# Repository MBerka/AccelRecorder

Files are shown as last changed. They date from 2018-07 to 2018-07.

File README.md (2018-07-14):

This project contains PCB and firmware files for the AccelRecorder wearable, capable of recording tri-axial accelerations or, with firmware adjustments, communicating with a combined accelerometer/gyroscope chip. The byte-encoded output of the firmware can be parsed and interpreted with the PC-side software of the AccelPanel repository.

The Eagle files in /PCB that can be etched chemically via toner transfer, or exported for commercial PCB manufacturing.

The C project was written and compiled through Atmel Studio 7. Compiled binaries are available in /Hardware/Debug.

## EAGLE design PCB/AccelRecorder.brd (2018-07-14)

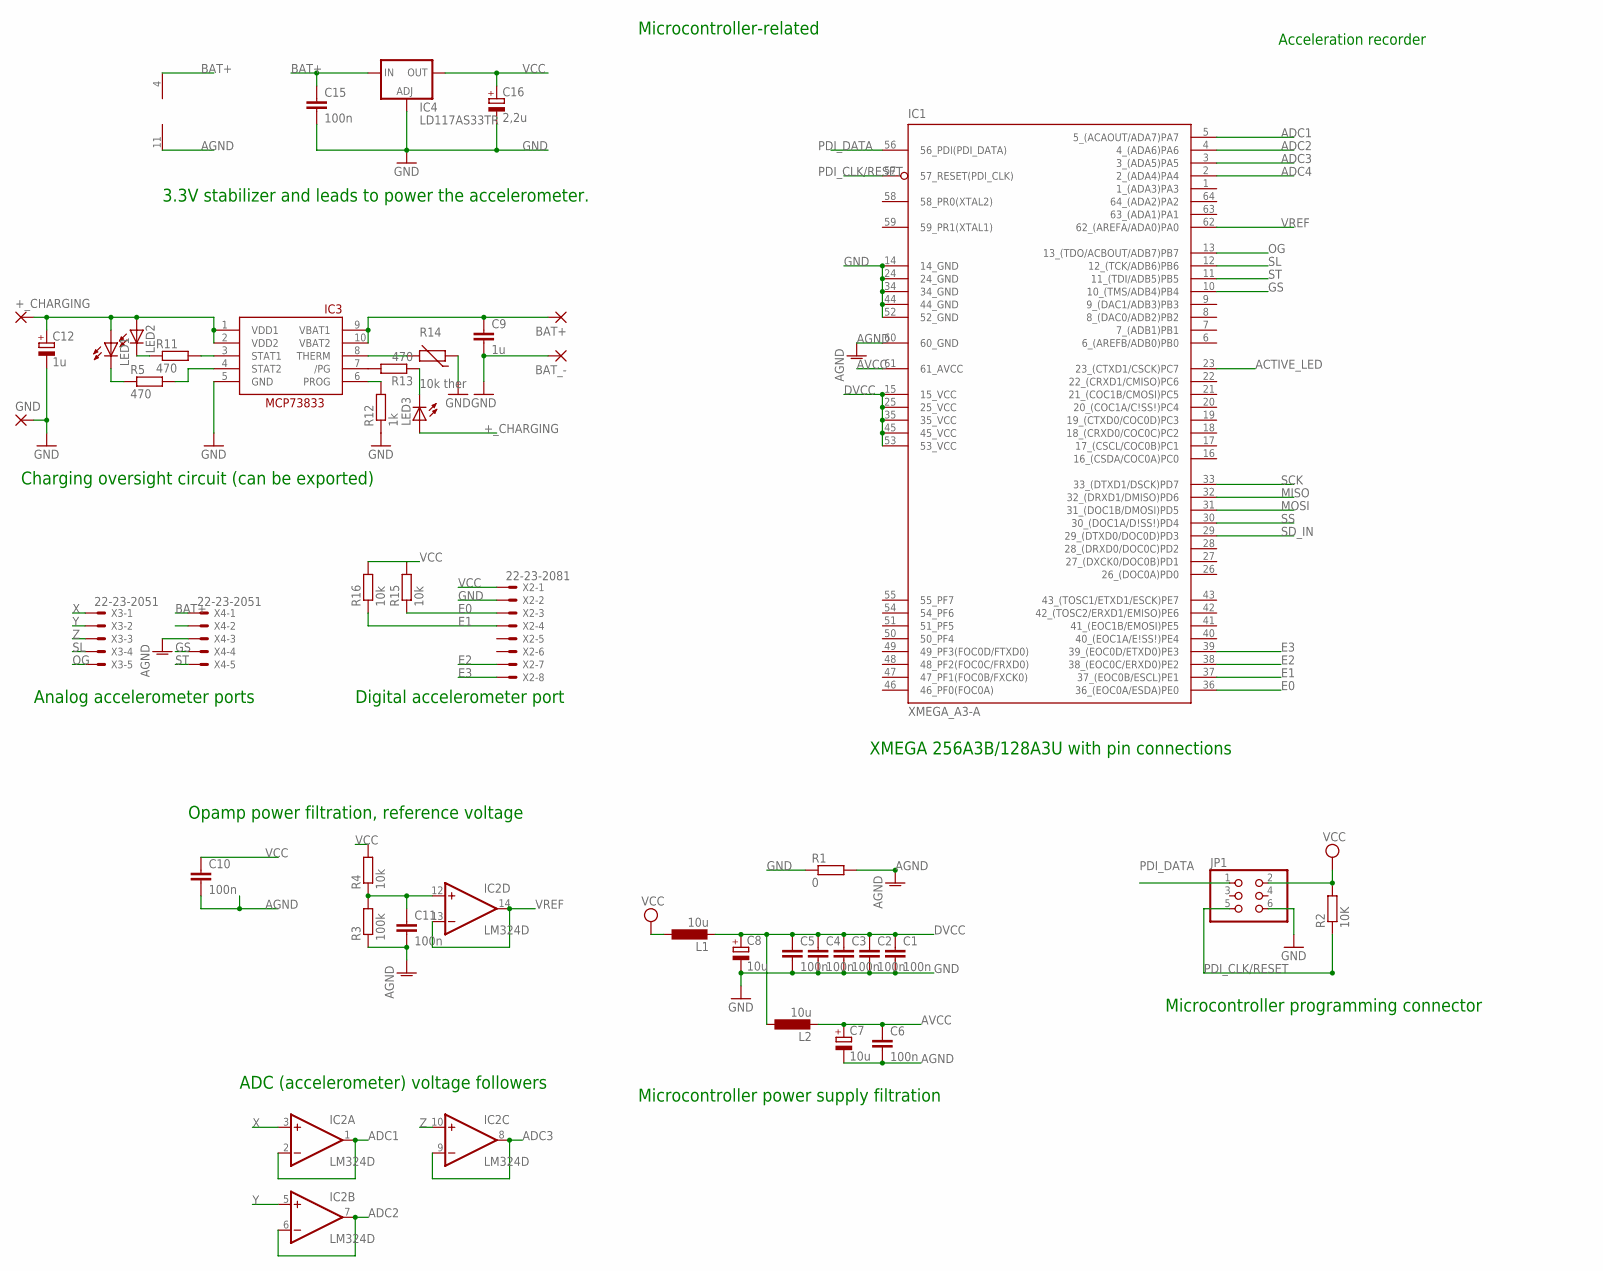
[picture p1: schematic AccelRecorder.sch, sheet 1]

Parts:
+_CHARGING: SMD2; SMD1,27-2,54
BAT+: SMD2; SMD1,27-2,54
BAT_-: SMD2; SMD1,27-2,54
C1, C2, C3, C4, C5, C6, C15: 100n; C0805K
C7, C8: 10u; SANYO-OSCON_SMD_B6
C9: 1u; C1206
C10, C11: 100n; C0805
C12: 1u; SANYO-OSCON_SMD_B6
C16: 2,2u; SANYO-OSCON_SMD_B6
GND: SMD2; SMD1,27-2,54
IC1: XMEGA_A3-A; TQFP64
IC2: LM324D; SO14
IC3: MCP73833-UN; MSOP10
IC4: LD117AS33TR; SOT223
JP1: PINHD-2X3; 2X03
L1, L2: 10u; L3225M
LED1, LED2, LED3: LED3MM
R1: 0; M1206
R2: 10K; M1206
R3: 100k; M1206
R4, R15, R16: 10k; M1206
R5, R11, R13: 470; R0805
R12: 1k; R0805
R14: 10k ther; RS-2,5
X2: 22-23-2081
X3, X4: 22-23-2051

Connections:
+_CHARGING: +_CHARGING.1, C12.+, IC3.1 (VDD1), IC3.2 (VDD2), LED1.A, LED2.A, LED3.A
ACTIVE_LED: IC1.23 (23_(CTXD1/CSCK)PC7); also elsewhere on the board
ADC1: IC1.5 (5_(ACAOUT/ADA7)PA7), IC2.1 (OUT), IC2.2 (-IN)
ADC2: IC1.4 (4_(ADA6)PA6), IC2.6 (-IN), IC2.7 (OUT)
ADC3: IC1.3 (3_(ADA5)PA5), IC2.8 (OUT), IC2.9 (-IN)
ADC4: IC1.2 (2_(ADA4)PA4)
AGND: C6.2, C7.-, C10.2, C11.2, IC1.60 (60_GND), IC2.11 (V-), R1.2, R3.1, X4.3
AVCC: C6.1, C7.+, IC1.61 (61_AVCC), L2.2
BAT+: BAT+.1, C9.1, C15.1, IC2.4 (V+), IC3.9 (VBAT1), IC3.10 (VBAT2), IC4.3 (IN), X4.1
DVCC: C1.1, C2.1, C3.1, C4.1, C5.1, C8.+, IC1.15 (15_VCC), IC1.25 (25_VCC), IC1.35 (35_VCC), IC1.45 (45_VCC), IC1.53 (53_VCC), L1.2, L2.1
E0: IC1.36 (36_(EOC0A/ESDA)PE0), R15.1, X2.3
E1: IC1.37 (37_(EOC0B/ESCL)PE1), R16.1, X2.4
E2: IC1.38 (38_(EOC0C/ERXD0)PE2), X2.7
E3: IC1.39 (39_(EOC0D/ETXD0)PE3), X2.8
GND: BAT_-.1, C1.2, C2.2, C3.2, C4.2, C5.2, C8.-, C9.2, C12.-, C15.2, C16.-, GND.1, IC1.14 (14_GND), IC1.24 (24_GND), IC1.34 (34_GND), IC1.44 (44_GND), IC1.52 (52_GND), IC3.5 (GND), IC4.1 (ADJ), JP1.6, R1.1, R12.1, R14.1, X2.2; also elsewhere on the board
GS: IC1.10 (10_(TMS/ADB4)PB4), X4.4
MISO: IC1.32 (32_(DRXD1/DMISO)PD6); also elsewhere on the board
MOSI: IC1.31 (31_(DOC1B/DMOSI)PD5); also elsewhere on the board
unnamed: IC3.7 (/PG), R13.2
unnamed: LED3.K (C), R13.1
unnamed: IC3.3 (STAT1), R11.2
unnamed: LED2.K (C), R11.1
unnamed: C11.1, IC2.12 (+IN), R3.2, R4.1
unnamed: IC3.6 (PROG), R12.2
unnamed: IC3.8 (THERM), R14.2
unnamed: LED1.K (C), R5.1
unnamed: IC3.4 (STAT2), R5.2
OG: IC1.13 (13_(TDO/ACBOUT/ADB7)PB7), X3.5
PDI_CLK/RESET: IC1.57 (57_RESET(PDI_CLK)), JP1.5, R2.1
PDI_DATA: IC1.56 (56_PDI(PDI_DATA)), JP1.1
SCK: IC1.33 (33_(DTXD1/DSCK)PD7); also elsewhere on the board
SD_IN: IC1.29 (29_(DTXD0/DOC0D)PD3); also elsewhere on the board
SL: IC1.12 (12_(TCK/ADB6)PB6), X3.4
SS: IC1.30 (30_(DOC1A/D\!SS\!)PD4); also elsewhere on the board
ST: IC1.11 (11_(TDI/ADB5)PB5), X4.5
VCC: C10.1, C16.+, IC4.4 (OUT), JP1.2, L1.1, R2.2, R4.2, R15.2, R16.2, X2.1; also elsewhere on the board
VREF: IC1.62 (62_(AREFA/ADA0)PA0), IC2.13 (-IN), IC2.14 (OUT)
X: IC2.3 (+IN), X3.1
Y: IC2.5 (+IN), X3.2
Z: IC2.10 (+IN), X3.3

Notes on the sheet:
Microcontroller-related
Microcontroller programming connector
Microcontroller power supply filtration
XMEGA 256A3B/128A3U with pin connections
Acceleration recorder
Opamp power filtration, reference voltage
ADC (accelerometer) voltage followers
Charging oversight circuit (can be exported)
3.3V stabilizer and leads to power the accelerometer.
Analog accelerometer ports
Digital accelerometer port

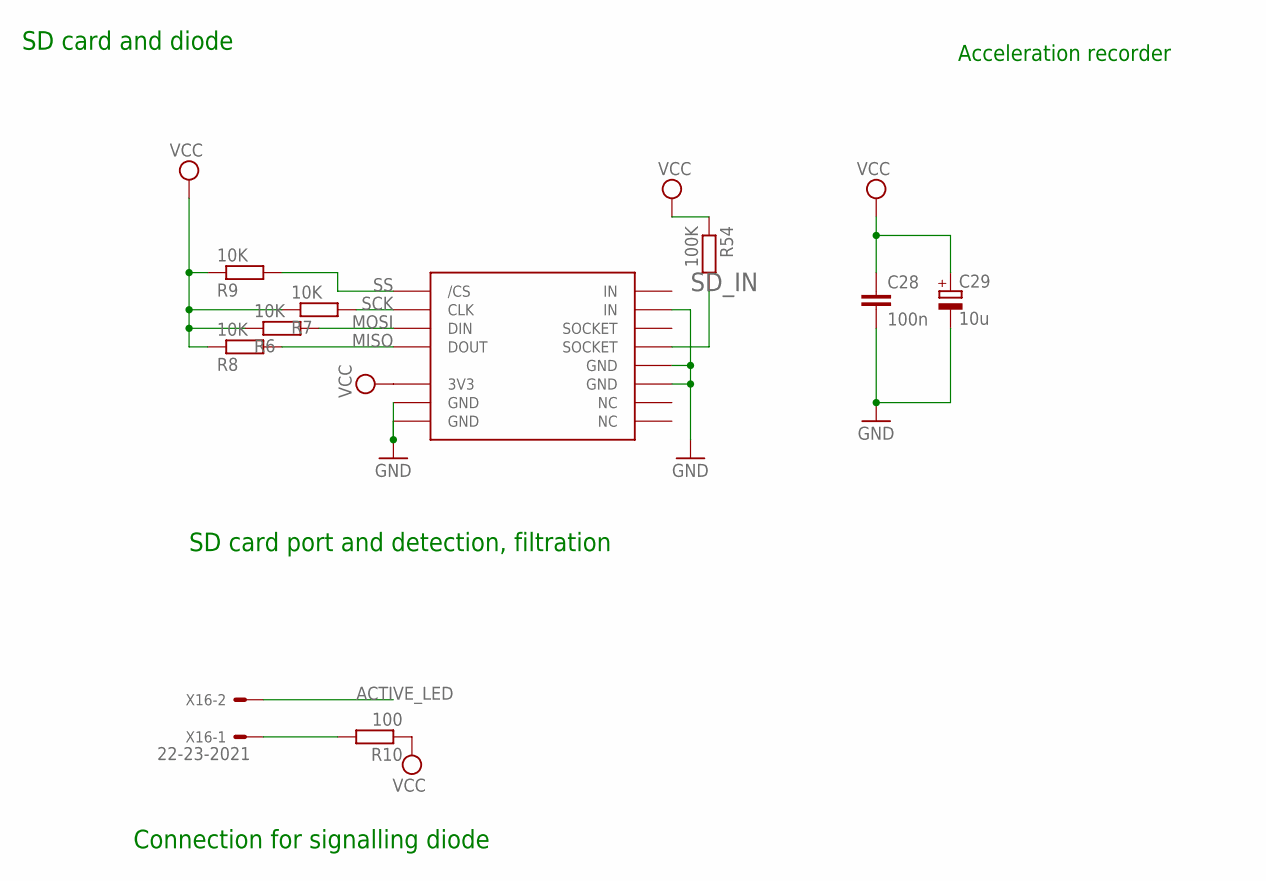
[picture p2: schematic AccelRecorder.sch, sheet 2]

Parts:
C28: 100n; C0805K
C29: 10u; SANYO-OSCON_SMD_B6
R6, R7, R8, R9: 10K; M1206
R10: 100; M1206
R54: 100K; M1206
U$1: MMC; MMC_SOCKET
X16: 22-23-2021; MPN 22-23-2021

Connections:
ACTIVE_LED: X16.2; also elsewhere on the board
GND: C28.2, C29.-, U$1.GND@1 (GND), U$1.GND@2 (GND), U$1.GND@3 (GND), U$1.GND@4 (GND), U$1.IN@2 (IN); also elsewhere on the board
MISO: R8.2, U$1.DOUT; also elsewhere on the board
MOSI: R6.2, U$1.DIN; also elsewhere on the board
unnamed: R10.2, X16.1
SCK: R7.2, U$1.CLK; also elsewhere on the board
SD_IN: R54.2, U$1.P$2 (SOCKET); also elsewhere on the board
SS: R9.2, U$1./CS; also elsewhere on the board
VCC: C28.1, C29.+, R6.1, R7.1, R8.1, R9.1, R10.1, R54.1, U$1.3V3; also elsewhere on the board

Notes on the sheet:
SD card and diode
SD card port and detection, filtration
Acceleration recorder
Connection for signalling diode

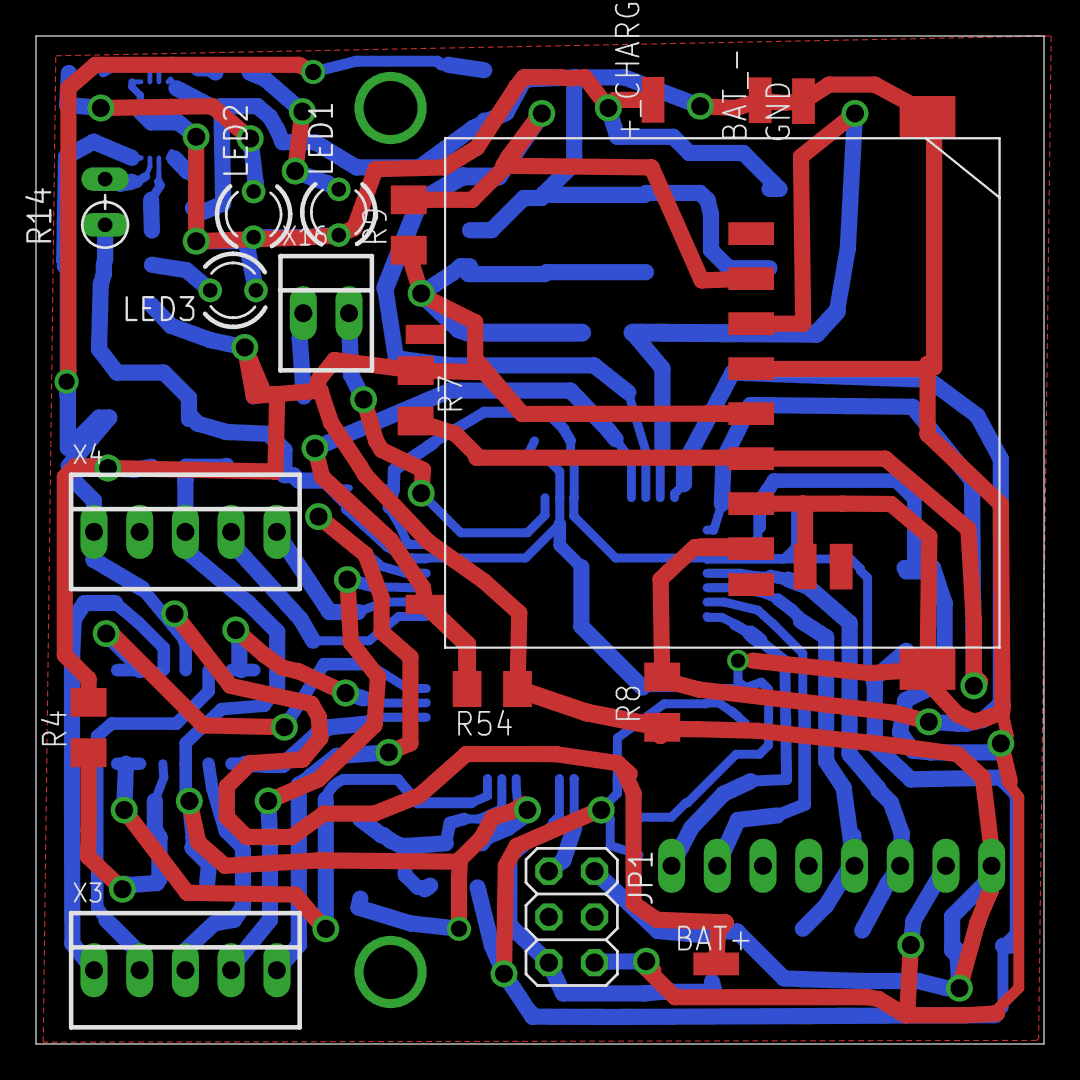
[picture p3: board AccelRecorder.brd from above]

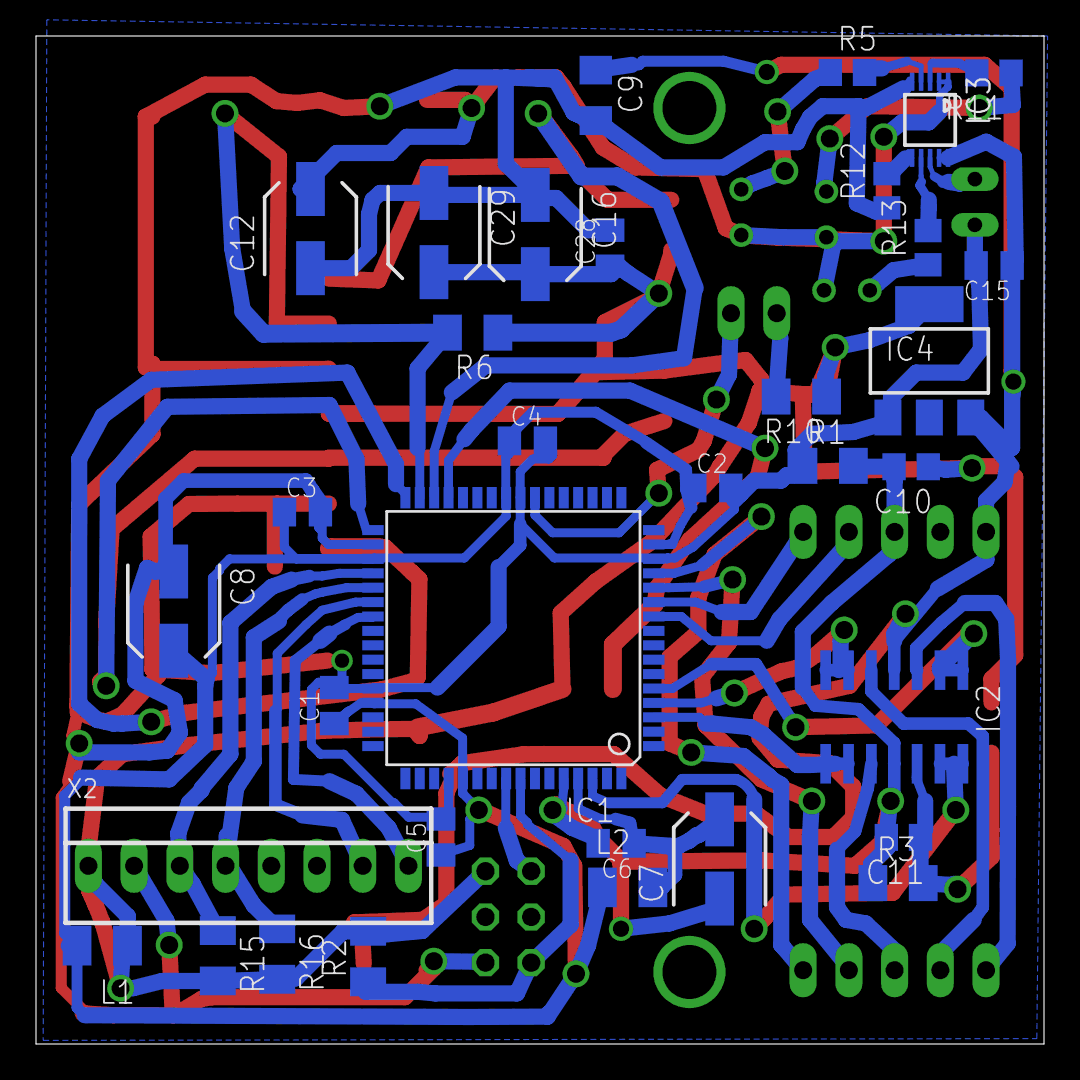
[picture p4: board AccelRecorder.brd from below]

Board: 2 copper layers, 56.0 x 56.0 mm, 52 parts (34 on the bottom side), 40 nets.

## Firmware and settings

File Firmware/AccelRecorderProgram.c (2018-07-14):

/*
 * AccelRecorderProgram.c
 * 26bytes/meas*300meas/s*3600s/h*48h
 *
 * Created: 2014-07-04 12:00:00
 * Author: Martin Berka, file access process reused from code by Marek Zylinski
 * When SD card is inserted, activates accelerometer and  records 300 
 * measurements/s from 3 ADC channels to SD Card while flashing diode.
 * Otherwise, enters low-power mode.
 */ 

#define F_CPU 16000000UL

#include <avr/io.h>
#include <util/delay.h>
#include <avr/pgmspace.h>
#include <avr/interrupt.h>
#include <string.h>
#include <math.h>
#include <stdio.h>

#include "xitoa.h"
#include "ff.h"
#include "diskio.h"

#include "avr_compiler.h"
#include "adc_driver.h"
#include "clksys_driver.h"
// #include "rtc32_driver.h" //Real-time clock not in use.
#include "wdt.h"

#define P_DIODE PIN7_bm //Pin for the communication diode — MSB, 128
#define LEDPORT PORTC //Port with the diode. Pins 0-6 are empty
#define AD_XYZ_PORT PORTA //Port with the accelerometer axes' voltages
#define P_XYZ 224 //Accelerometer data pins: 5, 6, 7.
#define AD_AUX_PORT PORTB //Port for steering the accelerometer, 0g detection; ADC/DAC
#define P_AUX_CONTROL 112 //Steering with pins 4,5,6: 
//gravity select (1.5g vs 6g), self-test (off, on), sleep (on, off): power saving=clear all
#define ACC_ACTIVE 80 //Pins 4 and 6: when high, sleep off, 6g sensitivity

volatile uint8_t file_num  = 1;
const uint8_t seconds_before_flashing = 4;

volatile unsigned char results_file[15] = {"0\0"};
volatile unsigned char list_file[15] = {"0\0"};
	
//Key boolean variables
volatile uint8_t recording = 0;
volatile uint8_t measuring = 0;

volatile uint8_t time = 0;//Given time of exercise
volatile uint8_t state = 0;//Specifies diodes to light
volatile uint8_t time_counter = 0;

//ADC variables
volatile uint8_t results_flag = 0;
volatile uint16_t result[3];
uint8_t channels[8] = {ADC_CH_MUXPOS_PIN0_gc, ADC_CH_MUXPOS_PIN1_gc,ADC_CH_MUXPOS_PIN2_gc,ADC_CH_MUXPOS_PIN3_gc,ADC_CH_MUXPOS_PIN4_gc,ADC_CH_MUXPOS_PIN5_gc,ADC_CH_MUXPOS_PIN6_gc,ADC_CH_MUXPOS_PIN7_gc};
uint8_t xyz_channel_numbers[3] = {5, 6, 7}; //Ostatnie 3 piny

volatile unsigned char str[44]={"0\0"};

//FatFs variables	
	FATFS fs;          // Work area (file system object) for the volume
	FIL fsrc;      /* file objects */
	FIL fzap;
	FIL flis;      /* file objects */
	FRESULT res;       // Petit FatFs function common result code
    char buff[120];     // File read buffer
    UINT br;           // File read count

void sleep_mode()
{
	sei();
	/* Choose sleep mode (power down, asynchronous I/O wakeup) */
	SLEEP.CTRL = SLEEP_SMODE_PDOWN_gc; 

	/* Disable timers on ports except D, which is needed to wake, and already-off E and F */
	PR.PRGEN  = 0x1F;
	PR.PRPA   = 0x7F;
	PR.PRPB   = 0x7F;
	PR.PRPC   = 0x7F;

	_delay_ms(6000.0);
	CCPWrite(&MCU.MCUCR, 0x1);
// 	PORTB.DIR = 0xFF;
// 	PORTB.OUT = 0;

	SLEEP.CTRL |= SLEEP_SEN_bm;
	asm volatile ("sleep");
	for(;;);
}

void get_file_name ()
{
	volatile FILINFO fno;
	file_num = 0;
	results_file[12] = '\0'; //"0\0" TYTUL PLIKU Z DANYMI DO LISTY
	do
	{
		sprintf((char *)results_file, "ACCEL%03d.TXT",file_num); //Create results file with new number
		res = f_stat((const TCHAR*)results_file, &fno); //See if file exists
//  		if(res == 0)
//  		{
// 			f_open(&fzap,  results_file, FA_READ);
//  			if(f_size(&fzap)<1000)
//  			{
//  				res = 1; //Overwrite empty files
//  			}
// 			f_close(&fzap);
//  		}
		file_num++;
	} while ((res == 0)&&(file_num<1000)); //Keep looking until new file found or too many files exist
}

char KH(int numer)
{
	return (char)(numer/100+28);
}
char KL(int numer)
{
	return (char)(numer%100+28);
}

int main(void)
{
	wdt_disable();
	PORTD_DIRCLR = PIN3_bm; //Input pin (detect SD card)
	PORTD.PIN3CTRL = PORT_OPC_PULLUP_gc;
	PORTD.INT0MASK = PIN3_bm;
//	PORTD.INTCTRL = PORT_INT0LVL_LO_gc;
	PORTD.INTCTRL = 0x0f;
	
//	PMIC.CTRL |= PMIC_LOLVLEN_bm;
/*	PORTS.PIN0CTRL = PORT_OPC_PULLUP_gc | PORT_ISC_FALLING_gc;
    PORTC.INT0MASK = PIN0_bm;
    PORTC.INTCTRL = PORT_INT0LVL_LO_gc;*/
	
	PR.PRPF   = 0x7F; //Nothing is connected to this port
	/** Disable the unused oscillators: 32 MHz, internal 32 kHz, external */
	OSC.CTRL &= ~(OSC_RC32MEN_bm | OSC_RC32KEN_bm);
	PORTF.DIR = 0;
	PORTF.PIN0CTRL = PORT_OPC_PULLUP_gc;
	PORTF.PIN1CTRL = PORT_OPC_PULLUP_gc;
	PORTF.PIN2CTRL = PORT_OPC_PULLUP_gc;
	PORTF.PIN3CTRL = PORT_OPC_PULLUP_gc;
	PORTF.PIN4CTRL = PORT_OPC_PULLUP_gc;
	PORTF.PIN5CTRL = PORT_OPC_PULLUP_gc;
	PORTF.PIN6CTRL = PORT_OPC_PULLUP_gc;
	PORTF.PIN7CTRL = PORT_OPC_PULLUP_gc;
	PORTE.DIR = 0; //Port E contains lines to an unused digital accelerometer
	//Modify if it is connected
	PORTE.PIN2CTRL = PORT_OPC_PULLUP_gc;	
	PORTE.PIN3CTRL = PORT_OPC_PULLUP_gc;
	PORTE.PIN4CTRL = PORT_OPC_PULLUP_gc;
	PORTE.PIN5CTRL = PORT_OPC_PULLUP_gc;
	PORTE.PIN6CTRL = PORT_OPC_PULLUP_gc;
	PORTE.PIN7CTRL = PORT_OPC_PULLUP_gc;	
	PR.PRPE   = 0x7F;
	
	recording = 0;
	LEDPORT.OUTTGL = P_DIODE;//Quick indication of startup

	//Ustawienie zegara na 16 MHz
  	CLKSYS_PLL_Config( OSC_PLLSRC_RC2M_gc, 8 );
	CLKSYS_Enable( OSC_PLLEN_bm );
	CLKSYS_Prescalers_Config( CLK_PSADIV_1_gc, CLK_PSBCDIV_1_1_gc );
	do {} while ( CLKSYS_IsReady( OSC_PLLRDY_bm ) == 0 );
	CLKSYS_Main_ClockSource_Select( CLK_SCLKSEL_PLL_gc );
	CLKSYS_Disable( OSC_XOSCEN_bm );
	
	//ADC calibration
	ADC_CalibrationValues_Load(&ADCA);
	ADC_ConvMode_and_Resolution_Config(&ADCA, ADC_ConvMode_Unsigned, ADC_RESOLUTION_12BIT_gc);
	ADC_Reference_Config(&ADCA, ADC_REFSEL_AREFA_gc);
	ADC_Prescaler_Config(&ADCA, ADC_PRESCALER_DIV8_gc);
	ADC_Ch_InputMode_and_Gain_Config(&ADCA.CH0,
	                                 ADC_CH_INPUTMODE_SINGLEENDED_gc,
	                                 ADC_CH_GAIN_1X_gc);							 
	ADC_Enable(&ADCA);
	ADC_Wait_8MHz(&ADCA);
	
	LEDPORT.DIR = P_DIODE; //Output to diode pin
	LEDPORT.OUT = P_DIODE; //Diode on
	
	AD_AUX_PORT.DIR = P_AUX_CONTROL; //Pins 4-6 control accelerometer
	AD_AUX_PORT.OUTCLR = P_AUX_CONTROL; //Asleep, self-test off, 1.5g sensitivity (all low)
	
	AD_XYZ_PORT.DIR = 0; //No outputs, some pins disconnected
			
	//Timer settings for ADC (successive measurements)
	TCD1.PERL = 50;             // 200 interrupts per second was 55L, 39H
	TCD1.PERH = 25;
    TCD1.CTRLA = 4;             // Prescaler 8
    TCD1.INTCTRLA = 2; 
	
	//Timer for measuring seconds
	TCC1.PERL = 25;                 // Set period 10000
	TCC1.PERH = 245;
	TCC1.CTRLA = 6;                // Prescaler  16
	TCC1.INTCTRLA = 3;                // Enable overflow interrupt
	PMIC_CTRL = 7; //PMIC.CTRL = PMIC_LOLVLEN_bm | PMIC_MEDLVLEN_bm | PMIC_HILVLEN_bm;
	                   // Enable medium level interrupts
		
	while(1)
	{
		if((PORTD.IN & _BV(3))) //Lowers power consumption when SD card removed; interrupt restores
		{
			sleep_mode();
		}
//		_delay_ms(100); //Czeka az bedzie karta - wstawienie tu prostego warunku nie dziala
		
		AD_AUX_PORT.OUTSET = ACC_ACTIVE; //Wake and set 6g
		
		if(recording==0) //Not currently recording; begin
		{
			time_counter = seconds_before_flashing;
			ENTER_CRITICAL_REGION(); //No interruptions
			res = 1;
			while (res != 0)
			{
				res = f_mount(0,&fs); //File system: mount SD card
			}
				
			//When ready, start file
			get_file_name();//Get name of file to write to
			//Open file for writing
			do 
			{
				res = f_open(&fzap,  results_file, FA_OPEN_ALWAYS | FA_WRITE);
			} while (res!=0);
			res = f_lseek(&fzap, f_size(&fzap)); //Jump to end
			
			sprintf((char *)str, "%c%c%c%c%c%c\n", KH(9898), KL(9898), KH(9898), KL(9898), KH(9898), KL(9898));
			//sprintf((char *)str, "%c%c%c%c%c%c%c%c%c%c%c%c%c%c%c%c\n", KH(9999), KL(9999), KH(9999), KL(9999),KH(9999),KL(9999),KH(9999), KL(9999), KH(9999), KL(9999),KH(9999),KL(9999),KH(9999), KL(9999),KH(9999), KL(9999));
			f_puts((const TCHAR*)str,&fzap);
			
			LEAVE_CRITICAL_REGION(); //Writing safe now
			
			recording = 1;
			LEDPORT.OUTCLR = P_DIODE;//Diode on
		}
	
		sei(); //Interrupts on
		while(recording) //Recording loop, active throughout most of program execution
		{			
			if (results_flag)
			{	
				ENTER_CRITICAL_REGION();			
				f_puts(str,&fzap); //Write data produced in interrupt to file
				LEAVE_CRITICAL_REGION();
				results_flag = 0; //Do nothing until next interrupt
			}
		}
		cli(); //Interrupts on
	}
}

ISR(TCC1_OVF_vect) 
{ //Interrupt for measuring time (every second)
	if (recording) //When recording is active
	{
		LEDPORT.OUTSET = P_DIODE;
		//Periodic checking of conditions for further recording
		if((!measuring)||(PORTD.IN & _BV(3))) //If measurement data or card absent
		{
			recording = 0; //Halt
			AD_AUX_PORT.OUTCLR = P_AUX_CONTROL; //Accelerometer: sleep; SL, ST, GS low
			return;
		}
	
		measuring = 0; //Should be set to true again before next such interrupt
		
		if(time_counter > 0)
		{ 
			time_counter--; //countdown to next, longer time interval
		}
		
		//Insert time marker every second
		
		sprintf((char *)str, "%c%c%c%c%c%c\n", KH(9999), KL(9999), KH(9999), KL(9999), KH(9999), KL(9999));
		//sprintf((char *)str, "%c%c%c%c%c%c%c%c%c%c%c%c%c%c%c%c\n", KH(9999), KL(9999), KH(9999), KL(9999),KH(9999),KL(9999),KH(9999), KL(9999), KH(9999), KL(9999),KH(9999),KL(9999),KH(9999), KL(9999),KH(9999), KL(9999));
		ENTER_CRITICAL_REGION();
		f_puts((const TCHAR*)str,&fzap);
		if(time_counter == 0)
		{
			time_counter = seconds_before_flashing; 
			//Make recording permanent every 5 seconds
			f_sync(&fzap); //The last line in the file is always a time marker
			LEDPORT.OUTCLR = P_DIODE;  //Flashing to indicate that device is working
		}
		LEAVE_CRITICAL_REGION();
	}
}

ISR(TCD1_OVF_vect) 
{ //Performs ADC measurements and writes them to the file
	if (recording)
	{
		for (uint8_t i = 0; i<3; i++)
		{
			//ADC_Ch_InputMux_Config(&ADCA.CH0, channels[xyz_channel_numbers[i]], ADC_CH_MUXNEG_PIN0_gc);//Wybor kanalu: pretwarzacz A, pin +, pin -
			ADC_Ch_InputMux_Config(&ADCA.CH0, ((xyz_channel_numbers[i])<<3), ADC_CH_MUXNEG_PIN0_gc);//Wybor kanalu: pretwarzacz A, pin +, pin -
     		ADC_Ch_Conversion_Start(&ADCA.CH0);
			while(!ADC_Ch_Conversion_Complete(&ADCA.CH0));
			result[i] = ADC_ResultCh_GetWord(&ADCA.CH0);
		}

		measuring = 1;
		results_flag = 1;
		
		//printf("%c%c", (char)(wyniki[licznik]/100+skok), (char)(wyniki[licznik]%100+skok)); Podstawa kodowania uzytego na nastepnej linii
		sprintf((char *)str, "%c%c%c%c%c%c\n", KH(result[0]), KL(result[0]), KH(result[1]), KL(result[1]),KH(result[2]),KL(result[2]));
		//sprintf((char *)str, "%c%c%c%c%c%c%c%c%c%c%c%c%c%c%c%c\n", KH(result[0]), KL(result[0]), KH(result[1]), KL(result[1]),KH(result[2]),KL(result[2]), KH(result[3]), KL(result[3]), KH(result[4]), KL(result[4]),KH(result[5]),KL(result[5]), KH(result[6]), KL(result[6]), KH(result[7]), KL(result[7]));
	}
}

ISR(PORTD_INT0_vect)
{
    // Quick visual confirmation of startup
    LEDPORT.OUTTGL = P_DIODE;

//	CCPWrite( &RST.CTRL, RST_SWRST_bm ); //Inadequate
	//wdt_enable(WDTO_15MS); //Fully reset as soon as possible
	wdt_enable();
    while(1){};
}

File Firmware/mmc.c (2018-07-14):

/*-----------------------------------------------------------------------*/
/* MMCv3/SDv1/SDv2 (in SPI mode) control module  (C)ChaN, 2010           */
/*-----------------------------------------------------------------------*/

#include <avr/io.h>
#include "diskio.h"


/* Port controls  (Platform dependent) */
#define CS_LOW()	PORTD.OUTCLR = 0x10		/* CS=low */
#define	CS_HIGH()	PORTD.OUTSET = 0x10		/* CS=high */
#define SOCKINS		1//!(PORTD.IN &  PIN4_bm)	/* Card detected.   yes:true, no:false, default:true */
#define SOCKWP		0//(PINB & 0x20)		/* Write protected. yes:true, no:false, default:false */
#define	FCLK_SLOW()	SPID.CTRL =0xD0	/* Set slow clock (F_CPU / 64) */
#define	FCLK_FAST()	SPID.CTRL =0xD0		/* Set fast clock (F_CPU / 2) */


/*--------------------------------------------------------------------------

   Module Private Functions

---------------------------------------------------------------------------*/

/* Definitions for MMC/SDC command */
#define CMD0	(0)			/* GO_IDLE_STATE */
#define CMD1	(1)			/* SEND_OP_COND (MMC) */
#define	ACMD41	(0x80+41)	/* SEND_OP_COND (SDC) */
#define CMD8	(8)			/* SEND_IF_COND */
#define CMD9	(9)			/* SEND_CSD */
#define CMD10	(10)		/* SEND_CID */
#define CMD12	(12)		/* STOP_TRANSMISSION */
#define ACMD13	(0x80+13)	/* SD_STATUS (SDC) */
#define CMD16	(16)		/* SET_BLOCKLEN */
#define CMD17	(17)		/* READ_SINGLE_BLOCK */
#define CMD18	(18)		/* READ_MULTIPLE_BLOCK */
#define CMD23	(23)		/* SET_BLOCK_COUNT (MMC) */
#define	ACMD23	(0x80+23)	/* SET_WR_BLK_ERASE_COUNT (SDC) */
#define CMD24	(24)		/* WRITE_BLOCK */
#define CMD25	(25)		/* WRITE_MULTIPLE_BLOCK */
#define CMD55	(55)		/* APP_CMD */
#define CMD58	(58)		/* READ_OCR */


static volatile
DSTATUS Stat = STA_NOINIT;	/* Disk status */

static volatile
BYTE Timer1, Timer2;	/* 100Hz decrement timer */

static
BYTE CardType;			/* Card type flags */


/*-----------------------------------------------------------------------*/
/* Power Control  (Platform dependent)                                   */
/*-----------------------------------------------------------------------*/
/* When the target system does not support socket power control, there   */
/* is nothing to do in these functions and chk_power always returns 1.   */

static
int power_status (void)		/* Socket power state: 0=off, 1=on */
{
	return 1;
}

static
void power_on (void)
{

	PORTD.DIRSET = (0xB0);
	PORTD.OUTCLR = 0x10;

	SPID.CTRL =0xD2; //setup SPI: Master mode, MSB first, SCK phase low, SCK idle low preskaler 32
}

static
void power_off (void)
{
	SPID.CTRL =0x00;//Disable SPI


}



/*-----------------------------------------------------------------------*/
/* Transmit/Receive data from/to MMC via SPI  (Platform dependent)       */
/*-----------------------------------------------------------------------*/

/* Exchange a byte */
static
BYTE xchg_spi (		/* Returns received data */
	BYTE dat		/* Data to be sent */
)
{
	SPID.DATA = dat;
	while(!(SPID.STATUS & SPI_IF_bm));
	return SPID.DATA;
}

/* Send a data block */
static
void xmit_spi_multi (
	const BYTE *p,	/* Data block to be sent */
	UINT cnt		/* Size of data block */
)
{
	do {
		SPID.DATA = *p++; 
		while(!(SPID.STATUS & SPI_IF_bm));
		SPID.DATA = *p++; 
		while(!(SPID.STATUS & SPI_IF_bm));
	} while (cnt -= 2);
}

/* Receive a data block */
static
void rcvr_spi_multi (
	BYTE *p,	/* Data buffer */
	UINT cnt	/* Size of data block */
)
{
	do {
		SPID.DATA = 0xFF; 
		while(!(SPID.STATUS & SPI_IF_bm));
		*p++ = SPID.DATA;
		SPID.DATA = 0xFF; 
		while(!(SPID.STATUS & SPI_IF_bm));
		 *p++ = SPID.DATA;
	} while (cnt -= 2);
}



/*-----------------------------------------------------------------------*/
/* Wait for card ready                                                   */
/*-----------------------------------------------------------------------*/

static
int wait_ready (void)	/* 1:OK, 0:Timeout */
{
	BYTE d;


	Timer2 = 50;	/* Wait for ready in timeout of 500ms */
	do
		d = xchg_spi(0xFF);
	while (d != 0xFF && Timer2);

	return (d == 0xFF) ? 1 : 0;
}



/*-----------------------------------------------------------------------*/
/* Deselect the card and release SPI bus                                 */
/*-----------------------------------------------------------------------*/

static
void deselect (void)
{
	CS_HIGH();
	xchg_spi(0xFF);	/* Dummy clock (force DO hi-z for multiple slave SPI) */
}



/*-----------------------------------------------------------------------*/
/* Select the card and wait for ready                                    */
/*-----------------------------------------------------------------------*/

static
int select (void)	/* 1:Successful, 0:Timeout */
{
	CS_LOW();
	xchg_spi(0xFF);	/* Dummy clock (force DO enabled) */

	if (wait_ready()) return 1;	/* OK */
	deselect();
	return 0;	/* Timeout */
}



/*-----------------------------------------------------------------------*/
/* Receive a data packet from MMC                                        */
/*-----------------------------------------------------------------------*/

static
int rcvr_datablock (
	BYTE *buff,			/* Data buffer to store received data */
	UINT btr			/* Byte count (must be multiple of 4) */
)
{
	BYTE token;


	Timer1 = 20;
	do {							/* Wait for data packet in timeout of 200ms */
		token = xchg_spi(0xFF);
	} while ((token == 0xFF) && Timer1);
	if (token != 0xFE) return 0;	/* If not valid data token, retutn with error */

	rcvr_spi_multi(buff, btr);		/* Receive the data block into buffer */
	xchg_spi(0xFF);					/* Discard CRC */
	xchg_spi(0xFF);

	return 1;						/* Return with success */
}



/*-----------------------------------------------------------------------*/
/* Send a data packet to MMC                                             */
/*-----------------------------------------------------------------------*/

static
int xmit_datablock (
	const BYTE *buff,	/* 512 byte data block to be transmitted */
	BYTE token			/* Data/Stop token */
)
{
	BYTE resp;


	if (!wait_ready()) return 0;

	xchg_spi(token);					/* Xmit data token */
	if (token != 0xFD) {	/* Is data token */
		xmit_spi_multi(buff, 512);		/* Xmit the data block to the MMC */
		xchg_spi(0xFF);					/* CRC (Dummy) */
		xchg_spi(0xFF);
		resp = xchg_spi(0xFF);			/* Reveive data response */
		if ((resp & 0x1F) != 0x05)		/* If not accepted, return with error */
			return 0;
	}

	return 1;
}



/*-----------------------------------------------------------------------*/
/* Send a command packet to MMC                                          */
/*-----------------------------------------------------------------------*/
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
